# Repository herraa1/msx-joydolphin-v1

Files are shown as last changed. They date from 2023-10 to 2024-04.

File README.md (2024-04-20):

# Nintendo Gamecube controller adapter for MSX (msx-joydolphin) v1

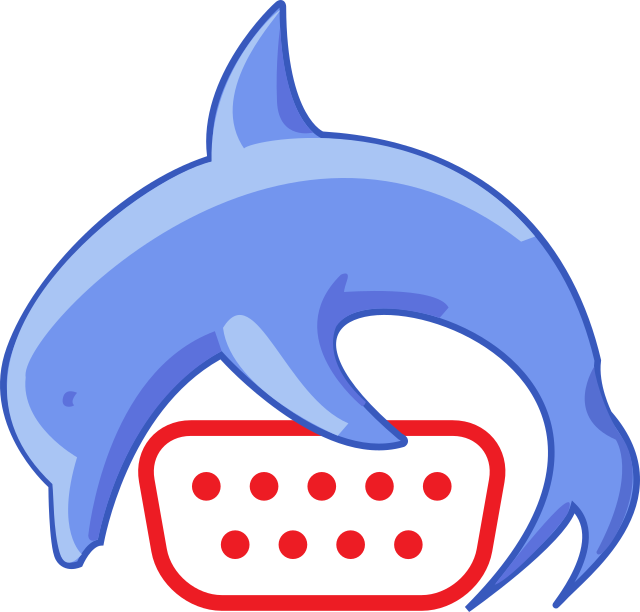
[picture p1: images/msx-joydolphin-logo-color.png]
[](images/msx-joydolphin-logo-color.png)

Connect [Nintendo Gamecube controllers](https://en.wikipedia.org/wiki/GameCube_controller) to [MSX computers](https://www.msx.org/wiki/).

> [!NOTE]
> [msx-joydolphin v2](https://github.com/herraa1/msx-joydolphin-v2) is now available!

## Introduction

The msx-joydolphin is an adapter that allows connecting Nintendo Gamecube controllers to [MSX general purpose ports](https://www.msx.org/wiki/General_Purpose_port).

The main features of the msx-joydolphin v1 adapter are:
* small footprint
* made of widely available electronic components
* behaves as a cord extension between the MSX computer and the Nintendo Gamecube controller
* uses a female standard DE9 connector on the adapter's MSX joystick side
* uses a Gamecube Controller socket on the adapter's Nintendo Gamecube controller side
* no need for external power supply for wired controllers, the adapter draws current from the MSX port
* low power consumption for wired controllers (<20mA)
* serial debug provides information about the operation of the adapter
* supports WaveBird Wireless Controllers (which draw up to 150mA) when powering the adapter via USB

## Adapter Name

Why msx-joydolphin?
The first part of the name is pretty obvious: _"msx"_ as this is an adapter for MSX computers and _"joy"_ as this is a joystick adapter.
The _"dolphin"_ part comes from the project codename assigned to the Nintendo Gamecube during its development.

## [Hardware](hardware/kicad/)

The msx-joydolphin v1 adapter uses an [Arduino Nano](https://store.arduino.cc/products/arduino-nano) to convert the [Nintendo Gamecube controller signalling](http://www.int03.co.uk/crema/hardware/gamecube/gc-control.html) to the [MSX joystick standard signalling](https://www.msx.org/wiki/Joystick_control).

A small printed circuit board (PCB) is used to easily bind all components:
* The Arduino Nano is connected using female headers
* PH2.0 connectors are used to connect cable extensions
* A 2.54 pitch debug header is added for convenience
* Through-hole components are used on the front side
* Surface mount device (SMD) components are used on the back side
  * The SMD components use footprints optimized for hand-soldering

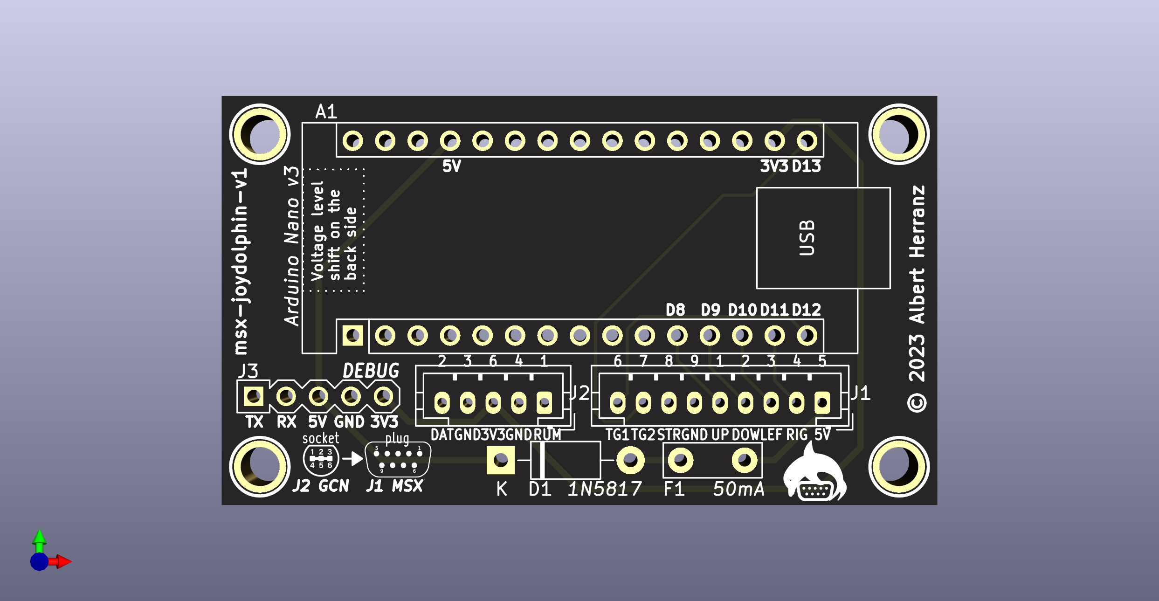
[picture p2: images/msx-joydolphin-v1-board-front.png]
[](images/msx-joydolphin-v1-board-front.png)
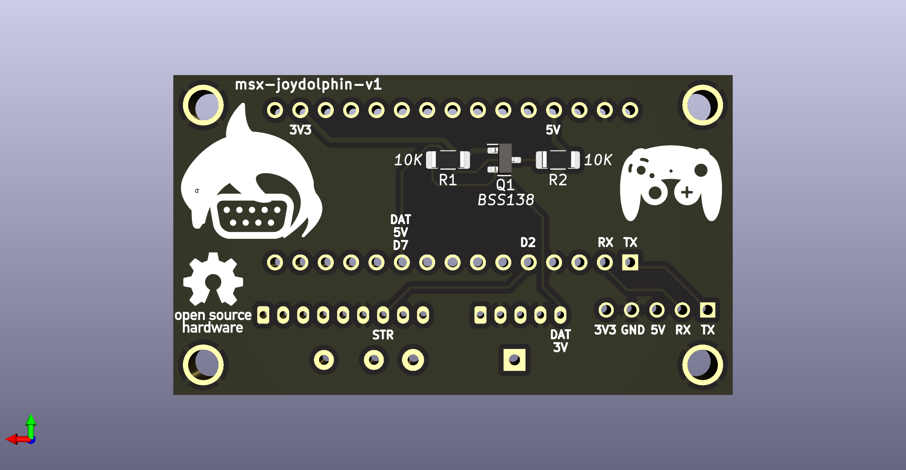
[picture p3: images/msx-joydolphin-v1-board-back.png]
[](images/msx-joydolphin-v1-board-back.png)

Connection to the MSX general purpose port is implemented using a DE9 joystick extension cable with a female DE9 connector on one side and a loose end on the other side.
The MSX joystick extension cable loose end is wired according to the following pinout mapping.

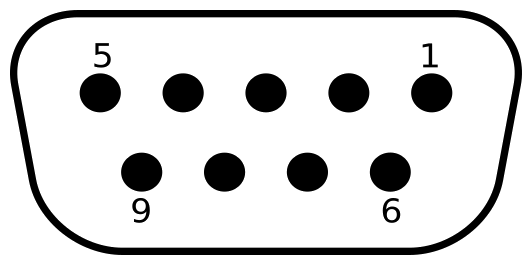
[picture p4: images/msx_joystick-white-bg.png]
| [](images/msx_joystick-white-bg.png) |
|:--|
| MSX joystick connector pinout, from controller plug side |

| MSX side pin | Cable color (may vary) | Signal | Arduino Nano side (port/pin/number) |
| --- | --- | --- | --- |
| 5 | Brown | +5v | _/5V/27 |
| 4 | Orange | RIGHT  | PB3/D11/14 |
| 3 | Grey | LEFT | PB2/D10/13 |
| 2 | Black | DOWN | PB1/D9/12 |
| 1 | Red | UP | PB0/D8/11 |
| 6 | Green | TRIGA  | PB4/D12/15 |
| 7 | White | TRIGB  | PB5/D13/16 |
| 8 | Blue | OUT | PD2/D2/5 |
| 9 | Yellow | GND | _/GND/4,29 |

The msx-joydolphin-v1 adapter ignores the MSX general purpose pin8 (OUT) signal. This is not a problem in general, but can cause incompatibilities with specific software, like MSX-HID [^2], which uses pin8 to try to guess which
kind of device is connected to a MSX general purpose I/O port. For MSX-HID, holding the Trigger B button, will put the software in FM-Towns compatible mode which will make the adapter functional.

The adapter uses open collector outputs (putting the related Arduino Nano pins in INPUT mode with pull-up registers active when in logic "1" and in OUTPUT mode LOW when in logic "0") which makes the adapter safer [^3] than the
standard MSX joystick schematic depicted in the MSX Technical Data Book, as it avoids a series of undesired conditions that can lead to bus contention/short circuits.

Power is drawn from the +5V signal of the MSX general purpose port, which is capable of delivering up to 50mA [^1].
The msx-joydolphin v1 draws below 20mA from the port when a wired controller is connected, so it is on the safe side. Anyway, the msx-joydolphin adapter uses a Positive Temperature Coeficient (PTC) resettable fuse of 50mA (F1) to limit current in case something goes wrong.

Also on the power side, a [1N5817 Schottky diode](https://www.onsemi.com/download/data-sheet/pdf/1n5817-d.pdf) (D1) is used to avoid leaking current from the msx-joydolphin adapter to the MSX in case the USB port of the Arduino Nano is connected to a computer or power supply while the adapter is plugged into an MSX.

Connection to the Nintendo Gamecube controller is done via a Nintendo Gamecube controller extension cable with a controller socket on one side and a loose end on the other side.
The Nintendo Gamecube controller extension cable loose end is wired according to the following pinout mapping.

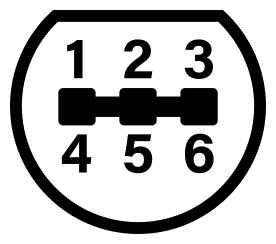
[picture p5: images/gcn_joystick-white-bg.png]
| [](images/gcn_joystick-white-bg.png) |
|:--|
| Nintendo Gamecube connector pinout, from Nintendo Gamecube side |

| Gamecube socket pin | Cable color official | Cable color actual (may vary) | Signal | Comment | Arduino Nano side (port/pin/number) |
| --- | ---| --- | --- | --- | --- |
| 1 | Yellow | White | +5v | rumble, not used | N/C |
| 2 | Red | Red | DAT | data line, uses 3v3 logic so it connects via a level shifter to PD7/D7/10 | \*( PD7/D7/10 ) |
| 3 | Green | Black | GND | ground | _/GND/4,29 |
| 4 | White | Blue | GND | ground | _/GND/4,29 |
| 5 | | | | | N/C |
| 6 | Blue | Green | 3.43v  | power line, 3v3 | _/3v3/17 |
| 7 | Black | N/A | GND | ground | N/C |

The Nintendo Gamecube controller uses 3.3V for power and logic, except for the rumble motor which uses 5V.

Power for the Nintendo Gamecube controller is provided by the 3.3V pin of the FT232RL integrated in the Arduino Nano, which is capable of delivering up to 50mA [^2], enough to power a wired game controller.

As the Arduino Nano is a 5V logic microcontroller, the msx-joydolphin adapter uses a voltage level shifter based on the [BSS138 N-Channel Logic Level Enhancement Mode Field Effect Transistor](https://www.onsemi.com/pdf/datasheet/bss138-d.pdf) (Q1) to convert the Nintendo Gamecube controller DAT signal between 3.3V and 5V logic levels.

> [!WARNING]
> Do NOT connect the DAT line of the Nintendo Gamecube controller to the Arduino Nano directly, always use a voltage level shifter.
> The game controller may get damaged if you connect a 5V signal directly to the 3.3V DAT line.

If a WaveBird Wireless Controller is connected then the msx-joydolphin adapter needs to be powered via the mini USB port of the Arduino Nano, as the power consumption (150mA) is higher than what the MSX joystick port can deliver.
Althought it won't work, it is safe to connect a WaveBird Wireless Controller dongle without connecting an external USB power supply thanks to the current limitation of the PTC.
Also, connection of an external USB power supply to the Arduino Nano won't back-power the MSX computer thanks to the Schottky diode reverse current protection.

## [Firmware](firmware/msx-joydolphin-v1/)

The msx-joydolphin v1 adapter firmware uses [NicoHood's Nintendo library](https://github.com/NicoHood/Nintendo) to read the Nintendo Gamecube controller status, and it is heavily inspired on [Daniel Jose Viana "Danjovic" firmware](https://github.com/Danjovic/MSX/blob/master/NSX-64) for a similar adapter for Nintendo 64 joysticks.

The following elements are used as inputs:
* digital pad (D-Pad), as direction arrows
* analog pad, as direction arrows
* A button, as Trigger 1
* B button, as Trigger 2

Those elements' status are processed by the msx-joydolphin firmware and transformed into MSX general purpose port's signals on the fly.

The firmware uses Arduino Nano's sleep capabilities to reduce power consumption when a wired controller is used.

## [Enclosure](enclosure/)

### Acrylic

A simple acrylic enclosure design for the project is provided to protect the electronics components and provide strain relief for the extension cords.

The enclosure uses a 3mm acrylic sheet.

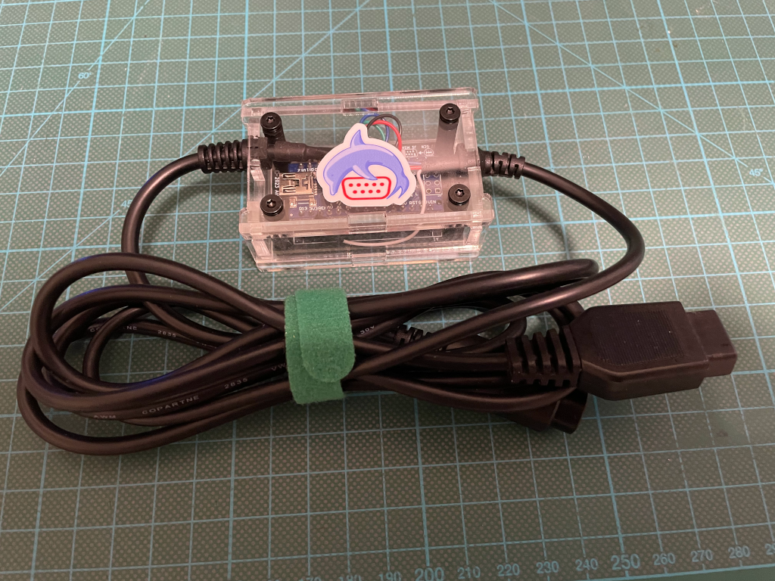
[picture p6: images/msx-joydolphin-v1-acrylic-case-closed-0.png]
[](images/msx-joydolphin-v1-acrylic-case-closed-0.png)
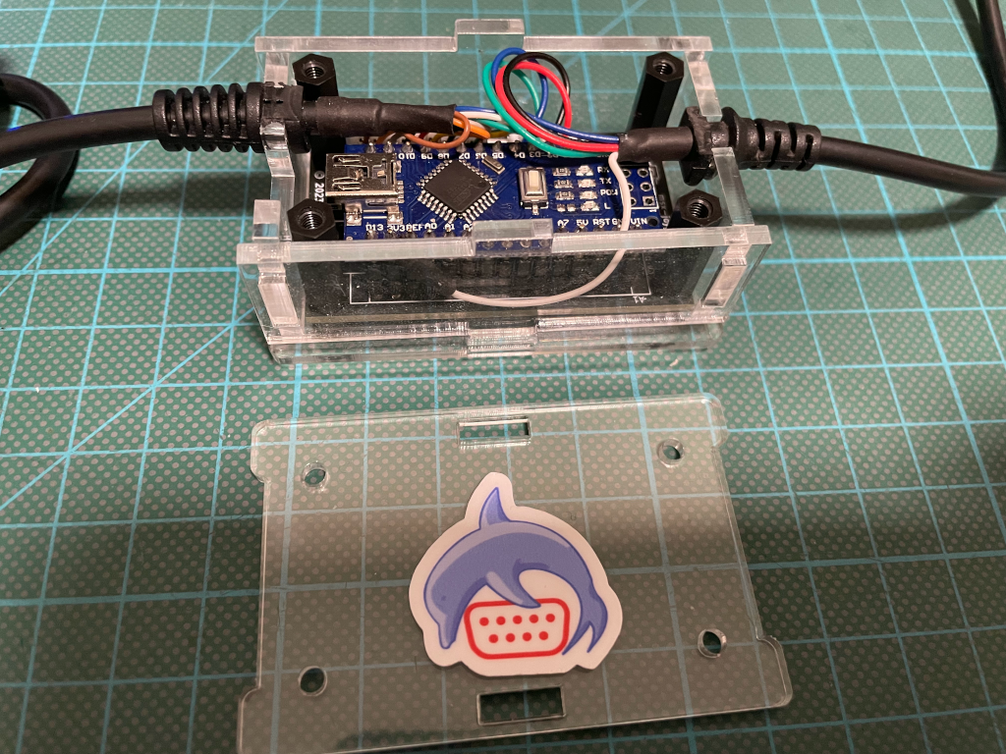
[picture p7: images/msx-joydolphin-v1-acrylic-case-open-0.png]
[](images/msx-joydolphin-v1-acrylic-case-open-0.png)
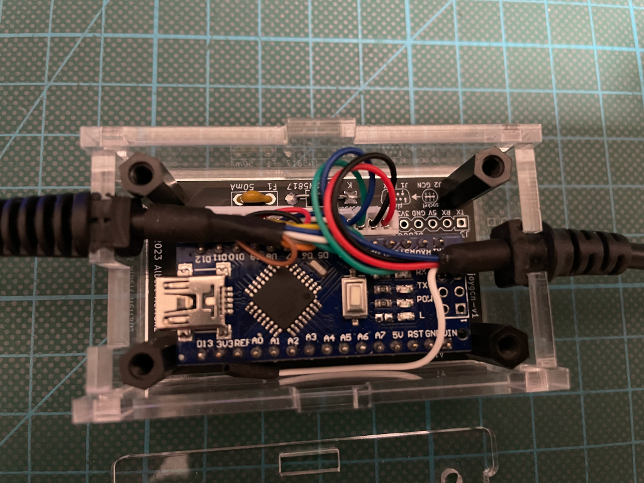
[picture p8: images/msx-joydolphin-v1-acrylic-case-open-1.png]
[](images/msx-joydolphin-v1-acrylic-case-open-1.png)

Later designs of the enclosure allow access to the USB port of the Arduino Nano without having to open it.

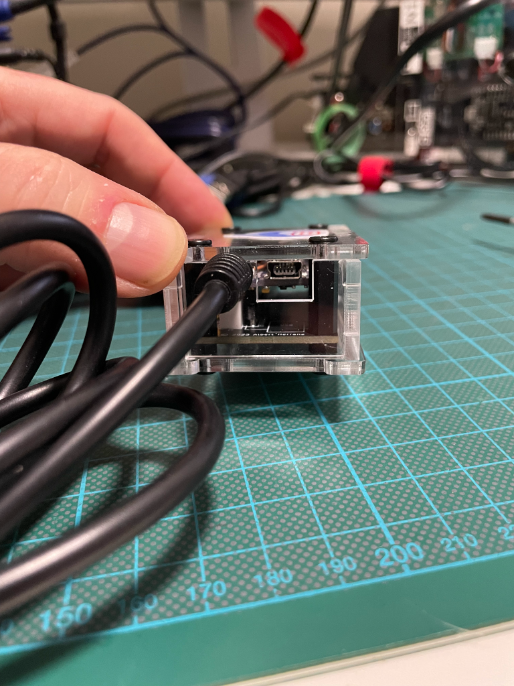
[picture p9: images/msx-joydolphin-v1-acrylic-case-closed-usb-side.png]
[](images/msx-joydolphin-v1-acrylic-case-closed-usb-side.png)

### Plastic

Another enclosure option is using an off-the-shelf plastic case of 60x36x17mm.

When using this option, the Arduino Nano must be soldered directly to the msx-joydolphin v1 board and its pin header legs must be trimmed down in order to fit within the reduced space of the case.

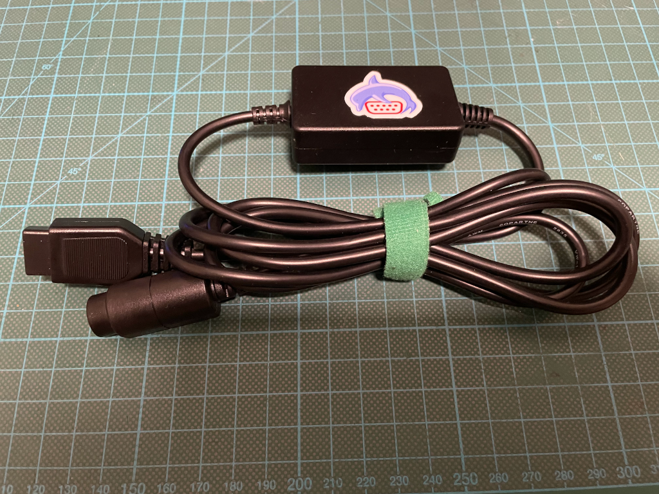
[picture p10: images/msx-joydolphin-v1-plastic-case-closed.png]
[](images/msx-joydolphin-v1-plastic-case-closed.png)
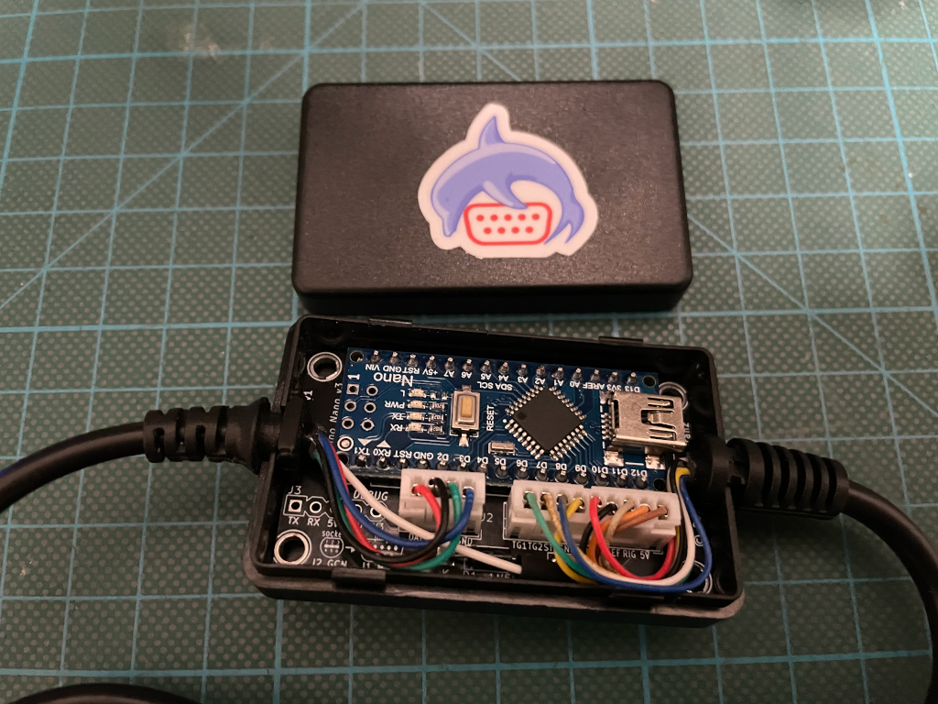
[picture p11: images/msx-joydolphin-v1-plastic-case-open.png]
[](images/msx-joydolphin-v1-plastic-case-open.png)

## References

MSX General Purpose port
* https://www.msx.org/wiki/General_Purpose_port

Gamecube controller pinout
* https://allpinouts.org/pinouts/connectors/videogame/nintendo-gamecube-controller-connector-pinout/
* http://www.int03.co.uk/crema/hardware/gamecube/gc-control.html

Arduino Nano pinout
* https://content.arduino.cc/assets/Pinout-NANO_latest.pdf
* https://www.makerguides.com/arduino-nano/

Nico Hood Nintendo Gamecube Joystick arduino library
* https://github.com/NicoHood/Nintendo

Daniel Jose Viana "Danjovic" NSX-64 project
* https://github.com/Danjovic/MSX/blob/master/NSX-64

Gamecube controller IDs
* https://www.gc-forever.com/yagcd/chap9.html#sec9

[^1]: https://www.msx.org/wiki/General_Purpose_port
[^2]: https://www.mouser.es/datasheet/2/163/DS_FT232R-11534.pdf
[^3]: https://www.msx.org/wiki/Joystick/joypad_controller (see "Undesired Conditions")

## Image Sources

* https://www.oshwa.org/open-source-hardware-logo/
* https://consolemods.org/wiki/images/a/a1/GameCube_Controller_Pinout.svg
* https://en.wikipedia.org/wiki/File:Numbered_DE9_Diagram.svg
* https://commons.wikimedia.org/wiki/File:Video_Game_Controller_(56427)_-_The_Noun_Project.svg
* https://logo-timeline.fandom.com/wiki/GameCube?file=Nintendo_Dolphin_1999.svg

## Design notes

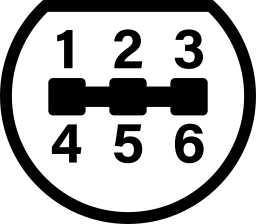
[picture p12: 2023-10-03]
images/gcn_joystick.png

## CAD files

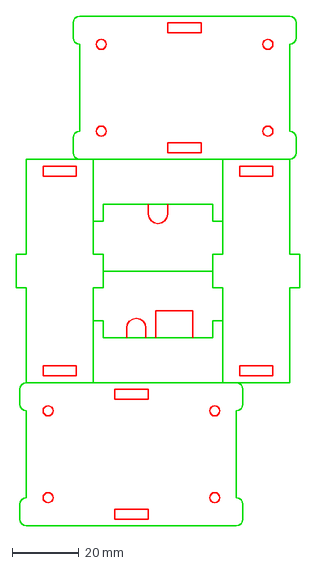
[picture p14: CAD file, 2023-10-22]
enclosure/msx-joydolphin-v1-case.dxf
85.0 x 153.0 mm

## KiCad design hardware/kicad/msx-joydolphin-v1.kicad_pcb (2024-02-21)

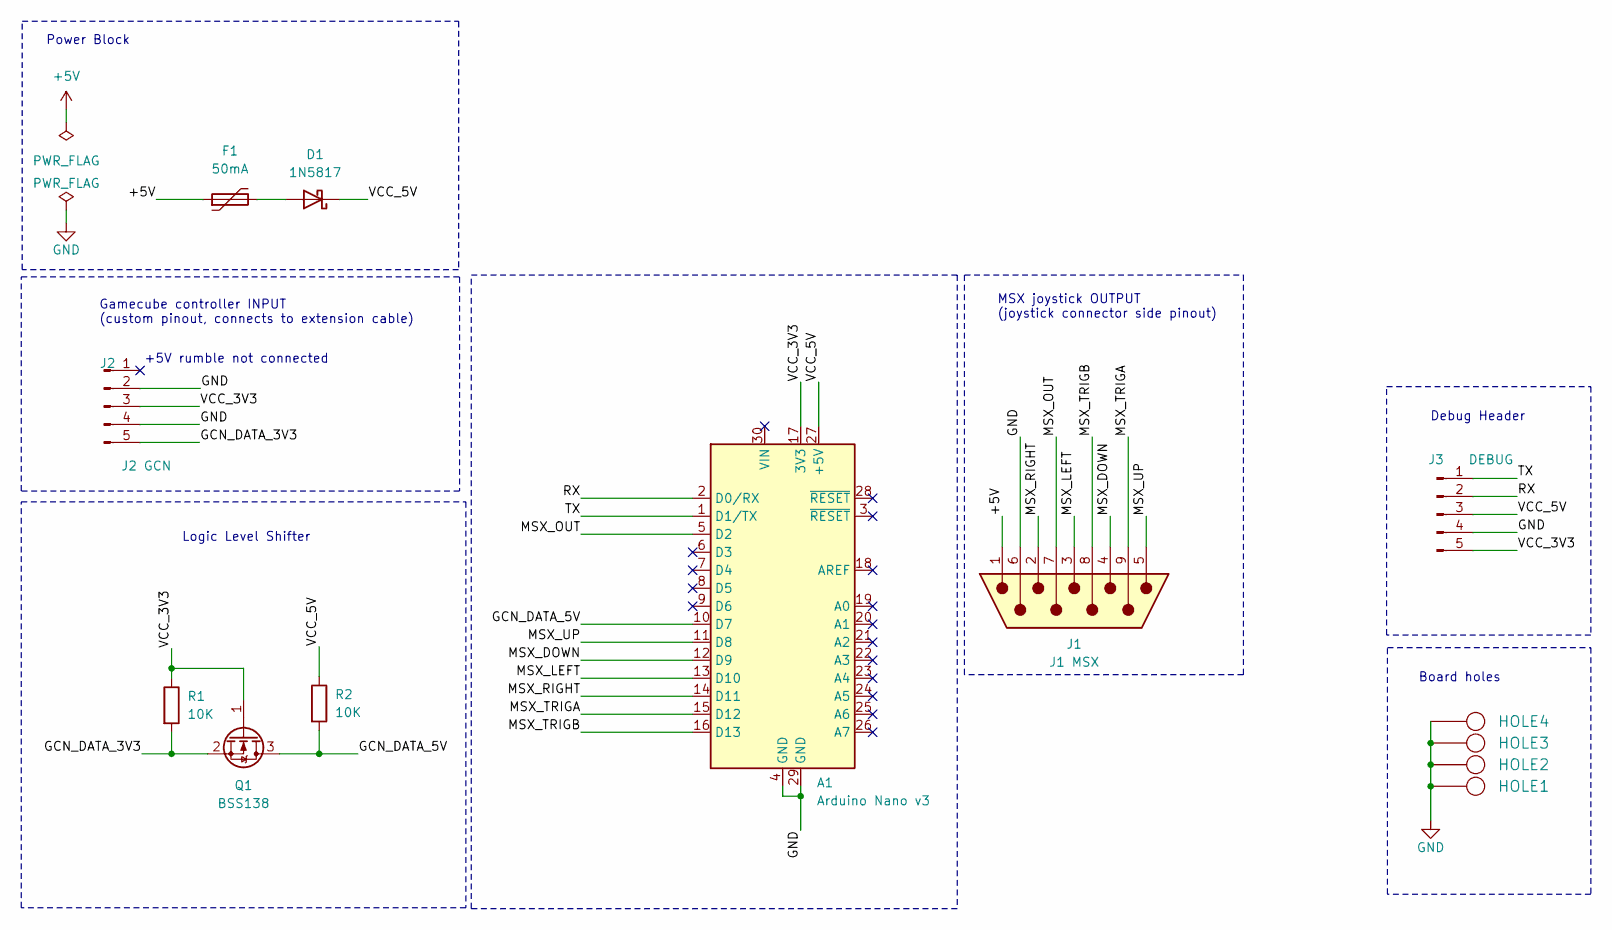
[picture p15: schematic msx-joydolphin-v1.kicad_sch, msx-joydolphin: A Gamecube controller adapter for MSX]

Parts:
A1: Arduino Nano v3; Arduino_Nano
D1: 1N5817; D_DO-41_SOD81_P10.16mm_Horizontal
F1: 50mA; C_Disc_D7.5mm_W2.5mm_P5.00mm
HOLE1, HOLE2, HOLE3, HOLE4: HOLE; Hole_3mm
J1: J1 MSX; JST_PH_B9B-PH-K_1x09_P2.00mm_Vertical
J2: J2 GCN; JST_PH_B5B-PH-K_1x05_P2.00mm_Vertical
J3: DEBUG; Conn_Pin_Header_5x1_2.54mm
Q1: BSS138; SOT-23
R1, R2: 10K; R_1206_3216Metric_Pad1.30x1.75mm_HandSolder

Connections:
+5V: F1.1, J1.1
/GCN_DATA_3V3: J2.5, Q1.2 (S), R1.2
/GCN_DATA_5V: A1.10 (D7), Q1.3 (D), R2.2
/MSX_DOWN: A1.12 (D9), J1.4
/MSX_LEFT: A1.13 (D10), J1.3
/MSX_OUT: A1.5 (D2), J1.7
/MSX_RIGHT: A1.14 (D11), J1.2
/MSX_TRIGA: A1.15 (D12), J1.9
/MSX_TRIGB: A1.16 (D13), J1.8
/MSX_UP: A1.11 (D8), J1.5
/RX: A1.2 (D0/RX), J3.2
/TX: A1.1 (D1/TX), J3.1
/VCC_3V3: A1.17 (3V3), J2.3, J3.5, Q1.1 (G), R1.1
/VCC_5V: A1.27 (+5V), D1.1 (K), J3.3, R2.1
GND: A1.4 (GND), A1.29 (GND), HOLE1.1, HOLE2.1, HOLE3.1, HOLE4.1, J1.6, J2.2, J2.4, J3.4
unnamed: D1.2 (A), F1.2

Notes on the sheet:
MSX joystick OUTPUT (joystick connector side pinout)
Debug Header
+5V rumble not connected
Board holes
Power Block
Logic Level Shifter
Gamecube controller INPUT (custom pinout, connects to extension cable)

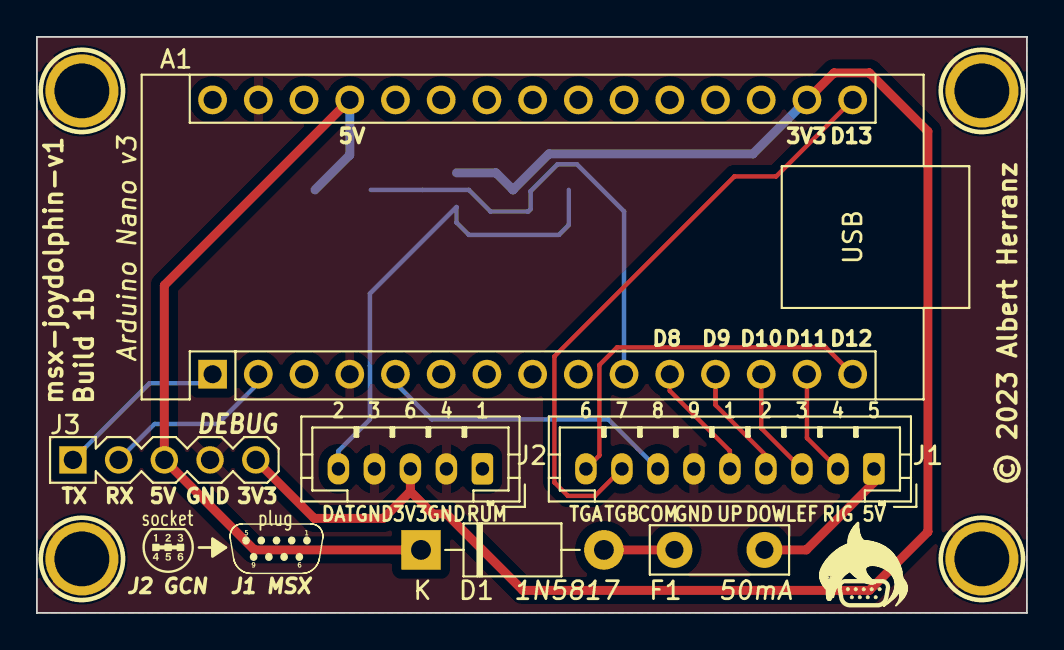
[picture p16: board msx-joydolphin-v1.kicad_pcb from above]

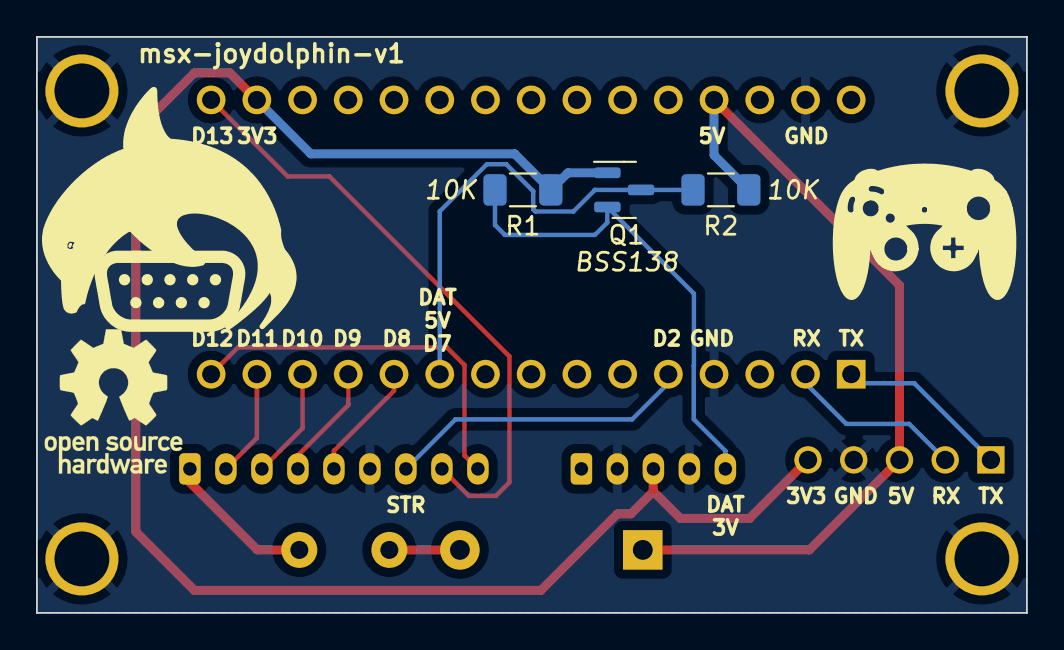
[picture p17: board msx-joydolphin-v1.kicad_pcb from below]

Board: 2 copper layers, 55.0 x 32.0 mm, 13 parts (3 on the bottom side), 16 nets.

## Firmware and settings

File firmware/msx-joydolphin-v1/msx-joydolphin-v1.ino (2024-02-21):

/*
 * msx-joydolphin, a Gamecube controller to MSX joystick adapter
 * Copyright (C) 2023 Albert Herranz
 *
 * This code is released under GPL V2.0
 *
 * Valid-License-Identifier: GPL-2.0-only
 * SPDX-URL: https://spdx.org/licenses/GPL-2.0-only.html
 *
 * Based on previous work by:
 * - Daniel Jose Viana "Danjovic" NSX-64 project, https://github.com/Danjovic/MSX/tree/master/NSX-64/firmware/nsx-64
 * - NicoHood Nintendo library, https://github.com/NicoHood
 *
 * Other references:
 * - http://www.int03.co.uk/crema/hardware/gamecube/gc-control.html
 * - https://www.msx.org/wiki/General_Purpose_port
 */

/*
 * NOTE
 *
 * The msx-joydolphin v1 adapter does not follow the joystick circuit diagram described in the
 * MSX Technical Data Book (Page 27, "1.4.6 Joysticks").
 *
 * This adapter ignores pin8 status and puts signals for joystick arrows/buttons in high impedance mode
 * (disconnected, pulled up to +5V by MSX pull-ups) except if the stick or trigger(s) are actuated in which
 * case the corresponding signals are pulled down to GND.
 *
 * This is functionally equivalent to a standard MSX joystick when pin8 is set to LOW which is required by software
 * to get the status of a joystick stick or trigger(s).
 */

#include <avr/sleep.h>
#include <avr/power.h>
#include <avr/interrupt.h>
#include "Nintendo.h"

/*
 * Debugging helpers
 */
/* #define DEBUG */

#ifdef DEBUG
  #define DEBUG_PRINTLN(x)  Serial.println (x)
#else
  #define DEBUG_PRINTLN(x)
#endif

/* Nintendo Gamecube controller pad axis valid range */
#define GCN_AXIS_MIN 0
#define GCN_AXIS_MAX 255

/*
 * Arduino Nano pins for MSX signals.
 * Use PORTB for all MSX joystick arrow and buttons signals.
 * This allows to set them all at the same time.
 */
#define PORT_MSX_JOYSTICK PORTB
#define DDR_MSX_JOYSTICK  DDRB

/* MSX general purpose signals as mapped to Arduino Nano PORTB bits */
const int PORT_MSX_JOYSTICK_UP       = 0; /* PB0, MSX joystick pin1 */
const int PORT_MSX_JOYSTICK_DOWN     = 1; /* PB1, MSX joystick pin2 */
const int PORT_MSX_JOYSTICK_LEFT     = 2; /* PB2, MSX joystick pin3 */
const int PORT_MSX_JOYSTICK_RIGHT    = 3; /* PB3, MSX joystick pin4 */
const int PORT_MSX_JOYSTICK_TRIGGER1 = 4; /* PB4, MSX joystick pin6 */
const int PORT_MSX_JOYSTICK_TRIGGER2 = 5; /* PB5, MSX joystick pin7 */ /* LED_BUILTIN */

/* Arduino Nano pin for MSX joystick pin8 signal */
const int MSX_JOYSTICK_STROBE   = 2; /* PD2, MSX joystick pin8 */ /* not used */

/* Nintendo Gamecube joystick controller */
CGamecubeController GamecubeController1(7); /* PD7 for DAT I/O */

volatile uint8_t curr_msx_joystick_signals = 0xff;

/*
 * Discrete thresholds for Nintengo Gamecube joystick analog pad axis:
 * - Values below the min threshold on the horizontal/vertical axis indicate
 *   left/down active, respectively.
 * - Values above the max threshold on the horizontal/vertical axis indicate
 *   right/up active, respectively.
 */
int axis_threshold_min, axis_threshold_max;

/* serial output width control */
uint8_t output_width_count = 0;

void print_hex8(uint8_t data)
{
    char tmp[2+1];
    byte nibble;

    nibble = (data >> 4) | 48;
    tmp[0] = (nibble > 57) ? nibble + (byte)39 : nibble;
    nibble = (data & 0x0f) | 48;
    tmp[1] = (nibble > 57) ? nibble + (byte)39 : nibble;
    tmp[2] = 0;

    Serial.print(tmp);
}

void print_hex16(uint16_t data)
{
    print_hex8((uint8_t)(data >> 8));
    print_hex8((uint8_t)(data & 0xff));
}

void print_rolling_sequence(void)
{
    static char rolling_chars[] = { '-', '\\', '|', '/' };
    static uint8_t rolling_index = 0;

    //Serial.write(8);
    Serial.print(rolling_chars[rolling_index++]);
    if (rolling_index >= sizeof(rolling_chars))
        rolling_index = 0;
}

void setup()
{
    int axis_threshold;

    /* initialize all joystick signals to high impedance */
    __update_msx_signals(0xff);

    /* use the serial port for debugging purposes */
    Serial.begin(9600);
    Serial.println("msx-joydolphin-v1 20240217_1");

    /*
     * Calculate Nintendo Gamecube controller analog pad thresholds.
     * Analog pad needs to be pushed from its origin in one direction at least
     * 1/6 of the complete run to get active
     */
    axis_threshold = (GCN_AXIS_MAX - GCN_AXIS_MIN) /3;
    axis_threshold_min = GCN_AXIS_MIN + axis_threshold;
    axis_threshold_max = GCN_AXIS_MAX - axis_threshold;

    GamecubeController1.begin(); /* initialize controller */
}

void loop()
{
    loop_gamecube_controller();
}

inline void __update_msx_signals(uint8_t signals)
{
    /*
     * signals variable bit definitions
     * bit5  bit4  bit3  bit2  bit1  bit0
     * TRG2  TRG1  RIGHT LEFT  DOWN  UP
     *
     * - bit set   : joystick arrow/button is not pressed
     *               configure associated GPIO as HIGH/INPUT (high impedance, logic "Z")
     * - bit unset : joystick arrow/button is pressed
     *               configure associated GPIO as LOW/OUTPUT (logic "0")
     *
     * In high impendance, the MSX receives a logic "1" signal because of the
     * MSX PSG circuit internal pull-ups.
     * In logic "0", the MSX receives a logic "0" as the GPIO drives the signal to GND.
     *
     * WARNING! IMPORTANT! WARNING! IMPORTANT!
     *
     * We _MUST NOT_ and we _DON'T_ set the Arduino GPIOs controlling the MSX signals as HIGH/OUTPUT
     * as that could fry the Arduino or PSG if this adapter is connected to the MSX _AND_ any
     * MSX software _NOT DESIGNED FOR DRIVING JOYSTICKS_ but other peripherals is currently
     * executing on the MSX in this specific circumstances:
     * - adapter connected to port #1, TRG1 not pressed
     *   - Bit0 of PSG Reg15 is clear (0), driving joystick #1 Pin6 to GND
     *   - (GameCube controller A button is not pressed)
     *   - Arduino D12/PB4 is incorrectly configured as HIGH/OUTPUT, driving joystick #1 Pin6 to +5V
     *   - we get bus contention on joystick #1 Pin6 bus
     * - adapter connected to port #1, TRG2 not pressed
     *   - Bit1 of PSG Reg15 is clear (0), driving joystick #1 Pin7 to GND
     *   - (GameCube controller B button is not pressed)
     *   - Arduino D13/PB5 is incorrectly configured as HIGH/OUTPUT, driving joystick #1 Pin7 to +5V
     *   - we get bus contention on joystick #1 Pin7 bus
     * - adapter connected to port #2, TRG1 not pressed
     *   - Bit2 of PSG Reg15 is clear (0), driving joystick #2 Pin6 to GND
     *   - (GameCube controller A button is not pressed)
     *   - Arduino D12/PB4 is incorrectly configured as HIGH/OUTPUT, driving joystick #2 Pin6 to +5V
     *   - we get bus contention on joystick #2 Pin6 bus
     * - adapter connected to port #2, TRG2 not pressed
     *   - Bit3 of PSG Reg15 is clear (0), driving joystick #2 Pin7 to GND
     *   - (GameCube controller B button is not pressed)
     *   - Arduino D13/PB5 is incorrectly configured as HIGH/OUTPUT, driving joystick #2 Pin7 to +5V
     *   - we get bus contention on joystick #2 Pin7 bus
     *
     * Thus we always _MUST_ and we _DO_ set GPIOs either as HIGH/INPUT ("Z") or LOW/OUTPUT ("0"),
     * as this firmware does.
     *
     * Note that the described failure scenario is impossible for MSX software written to interface
     * with joysticks because, in that case, bits 0-3 of PSG Reg15 are always set, not clear.
     * But we keep it safe anyway, just in case.
     */

    /*
     * NOTE! IMPORTANT! NOTE! IMPORTANT!
     *
     * This specific firmware version supports msx-joydolphin v1 boards which use D13/PB5 connected
     * to the TRG2 signal (pin7 of joystick connector).
     * D13/PB5 is (unfortunately) also connected within the Arduino Nano V3 board internally to a LED
     * (marked with "L" on the silkscreen) in series with a 1K resistor.
     * That Arduino internal 1K resistor form a voltage divider with a 10K pull-up resistor present in the
     * MSX circuitry (PSG uses open-collector with external pull-ups for those signals) which could
     * cause TRG2 to misbehave [1].
     * It will also cause the "L" LED to pull current from the MSX +5V via the MSX pull-up.
     *
     * To avoid problems with msx-joydolphin v1 Build1 adapters it is necessary to (choose one):
     * - Add a external pull up of 560 Ohm from D13/PB5 to +5V and keep the "L" LED and 1K resistor.
     * - Desolder either the "L" LED or the 1K resistor (in series with the "L" LED) from the Arduino
     *   Nano V3 board to convert D13/PB5 to a "normal" GPIO.
     *   Note that in recent Arduino Nano V3 boards it is not possible to desolder the 1K resistor as it
     *   is part of a resistor array connected too to the other three LEDs (power, rx, tx).
     * For Build2 and later adapters (when available) nothing needs to be done.
     *
     * [1] https://forum.arduino.cc/t/arduino-nano-pin-d13-usage/474254
     */

    /* write all signal states at once to MSX side */
    PORT_MSX_JOYSTICK = (signals);
    DDR_MSX_JOYSTICK = (~signals);
}

void loop_gamecube_controller()
{
    static bool was_connected = false;
    bool is_connected;
    uint16_t device;
    Gamecube_Report_t report;

    is_connected = GamecubeController1.connected();
    if (!is_connected) {
        /*
         * Make sure that no arrow/buttons stay pressed when
         * a gamecube controller is not connected.
         */
        curr_msx_joystick_signals = 0xff;

        /* write rolling sequence while not connected */
        print_rolling_sequence();
        /* wrap output at 80 columns ... */
        if (output_width_count++ > 79) {
            output_width_count = 0;
            Serial.println("");
        }
        was_connected = false;
    } else {
        if (!was_connected) {
            was_connected = true;
            device = GamecubeController1.getStatus().device;
            Serial.print("READY ");
            print_hex16(device);
            Serial.println("!");
            output_width_count = 0;
        }
    }

    /*
     * We need to read even if disconnected to make sure
     * that wavebird controllers connect properly (they use
     * a two stage connection process, as the dongle is always
     * connected but the controller only connects when activated).
     */
    if (GamecubeController1.read()) {
        uint8_t msx_joystick_signals = 0xff;

        report = GamecubeController1.getReport();

        /* Directional buttons (D-Pad) */
        if (report.dup)
            msx_joystick_signals &= ~(1<<PORT_MSX_JOYSTICK_UP);
        if (report.ddown)
            msx_joystick_signals &= ~(1<<PORT_MSX_JOYSTICK_DOWN);
        if (report.dleft)
            msx_joystick_signals &= ~(1<<PORT_MSX_JOYSTICK_LEFT);
        if (report.dright)
            msx_joystick_signals &= ~(1<<PORT_MSX_JOYSTICK_RIGHT);

        /*
        * Digital Equivalent to directional buttons using the analog stick.
        * From center/origin: up and right is positive, down and left is negative.
        */

        /* before activating UP check that DOWN is not activated */
        if ((report.yAxis > axis_threshold_max) && (msx_joystick_signals & (1<<PORT_MSX_JOYSTICK_DOWN)))
            msx_joystick_signals &= ~(1<<PORT_MSX_JOYSTICK_UP);

        /* before activating DOWN check that UP is not activated */
        if ((report.yAxis < axis_threshold_min) && (msx_joystick_signals & (1<<PORT_MSX_JOYSTICK_UP)))
            msx_joystick_signals &= ~(1<<PORT_MSX_JOYSTICK_DOWN);

        /* before activating LEFT check that RIGHT is not activated */
        if ((report.xAxis < axis_threshold_min) && (msx_joystick_signals & (1<<PORT_MSX_JOYSTICK_RIGHT)))
            msx_joystick_signals &= ~(1<<PORT_MSX_JOYSTICK_LEFT);

        /* before activating RIGHT check that LEFT is not activated */
        if ((report.xAxis > axis_threshold_max) && (msx_joystick_signals & (1<<PORT_MSX_JOYSTICK_LEFT)))
            msx_joystick_signals &= ~(1<<PORT_MSX_JOYSTICK_RIGHT);

        /* trigger buttons */
        if (report.a)
            msx_joystick_signals &= ~(1<<PORT_MSX_JOYSTICK_TRIGGER1);
        if (report.b)
            msx_joystick_signals &= ~(1<<PORT_MSX_JOYSTICK_TRIGGER2);

        curr_msx_joystick_signals = msx_joystick_signals;
    }
    __update_msx_signals(curr_msx_joystick_signals);
}

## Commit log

2023-10-03 Initial commit.
    [msx-joydolphin-v1-B_Cu.gbl, msx-joydolphin-v1-B_Mask.gbs, msx-joydolphin-v1-B_Paste.gbp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]
2023-10-21 Firmware improvements.
    - We can't use the builtin led as we use the pin for TRIG2,
    so now we use the TX led for reporting status
    - Wavebirds require at least 150mA which cannot be provided
    through the MSX joystick port. Now wavebirds work if
    the joydolphin is powered via the Nano usb port
    - Sleeping is now only enabled for wired controllers, as
    wavebirds do not work reliably while sleeping
    - Serial console information is improved
    [msx-joydolphin-v1.ino]
2023-10-21 Untested enclosure modification to allow USB port usage
    [msx-joydolphin-v1-case.dxf]
2023-10-22 enclosure: slightly move strain relief hole for msx extension, and regroup pieces
    [msx-joydolphin-v1-case.dxf]
2023-10-22 firmware: fix indentation error
    [msx-joydolphin-v1.ino]
2023-11-01 hardware: miscelanoues enhancements
    - Add top copper fill area for ground
    Save some chemicals when etching the top layer, and possibly enhance signal
    integrity.
    - Change board width
    Reduce board width from 56mm to 55mm to allow using alterante off-the-shelf
    plastic case.
    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
    [msx-joydolphin-v1.kicad_pcb]
2023-11-13 Fix spurious trigger 2 press on startup
    We are unfortunately using pin 13 of Arduino Nano for controlling trigger 2.
    That pin is hardwired to the builtin led which causes it to lit (slightly) when
    trigger 2 is not pressed and thus pulled high by the MSX side.
    It also causes a spurious press on startup.
    Instead of configuring the pin as input (high impedance) when trigger 2
    is not pressed, configure the pin as output and set it to high. When
    trigger 2 is pressed, the pin is configured as output and set to low as
    before.
    This makes de led light except when trigger 2 is pressed and avoids the
    spurious trigger on startup.
    This behaviour was detected when using the msx-joydolphin-v1 adapter
    on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
    [msx-joydolphin-v1.ino]
2023-11-14 Update readme to reflect new led behavior
2024-02-01 firmware: fixes unsafe TRG2 handling and aligns to standard joystick MSX behaviour on initial board revision
    [msx-joydolphin-v1.ino]
2024-02-01 readme: ignore arduino nano led
2024-02-17 firmware: revert to ignore pin8
    Due to the strict timings required to read the gamecube controller
    interrupts are disabled during those periods which lead to
    losing interrupts related to pin8 changes.
    Although the previous code passed the HIDtest test, observing
    the signals with a osciloscope reveals that some times pin8 is
    not honored correctly because of the lost pin8 change interrupts.
    As ignoring pin8 does not cause a change in behaviour when pin8 is
    low (as required to get the status of joysticks) vs a standard MSX
    joystick, we keep it this way.
    [msx-joydolphin-v1.ino]
2024-02-21 board: use OUT,TRGA,TRGB instead of STR,TRG1,TRG2
    [msx-joydolphin-v1.kicad_pcb, msx-joydolphin-v1.kicad_sch]

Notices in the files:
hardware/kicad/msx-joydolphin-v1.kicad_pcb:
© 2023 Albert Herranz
